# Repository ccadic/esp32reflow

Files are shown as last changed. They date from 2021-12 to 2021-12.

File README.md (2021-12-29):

# esp32reflow
Small prototype of ESP32 Reflow controller

Today's design: a small ESP32 based reflow controller. PCB made with KICAD. Enclosure made with solidworks. The features: ESP32 LOLIN32 LITE. ILI9341 2.8 display with touch option activated. MAX31865 the temperature probing. 4 buttons (3 on the panel, one on the rotary encoder).  a 110v/220v relay is also there to power the heater plate.  I'm sending the PCB to the factory . Once tested, I'll upload everything on github (opensource)

It is still a proto. I'm waiting for the PCB to arrive

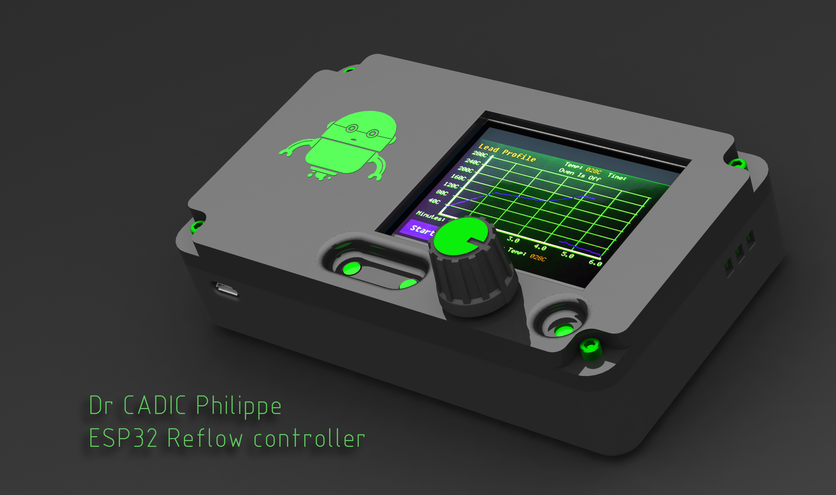
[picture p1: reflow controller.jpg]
reflow_controller


Here you have the first KICAD files
YOu also have the solidworks pre-prototyping files
ALl are subject to modification as the project gores on.

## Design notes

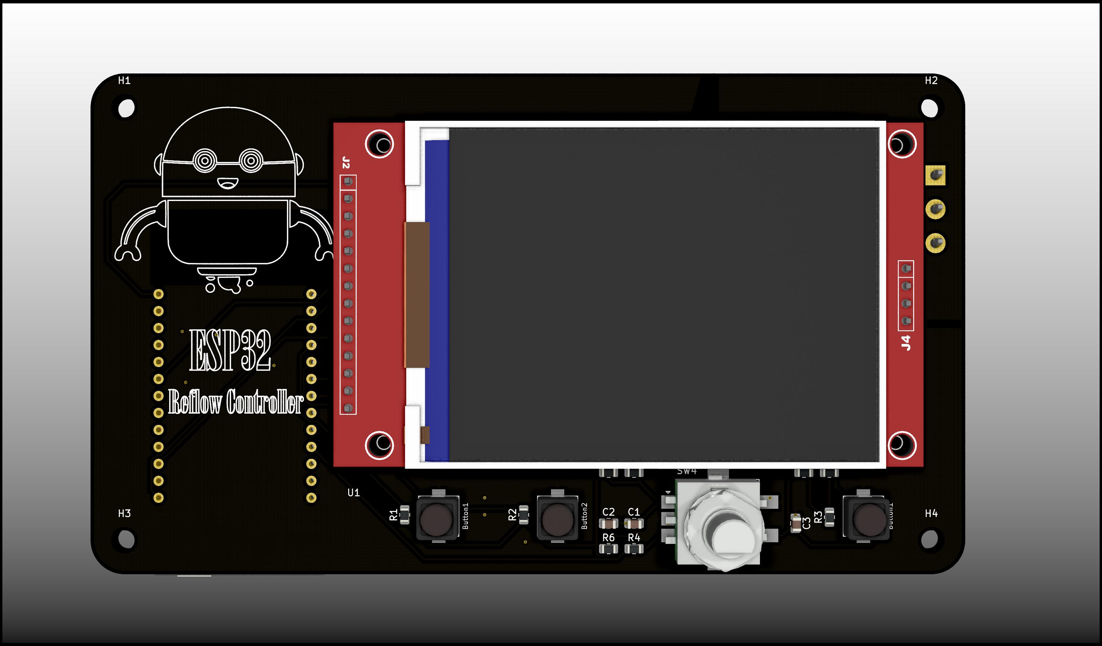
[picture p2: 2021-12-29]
esp32pcbheaterx.jpg

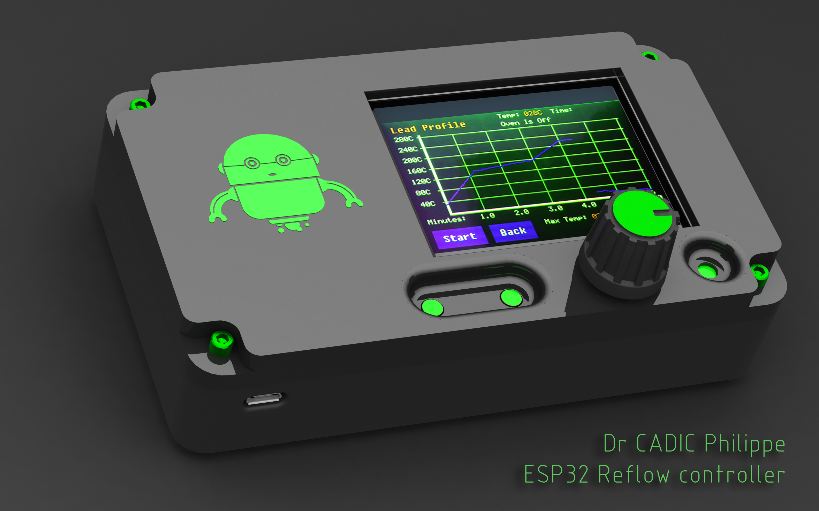
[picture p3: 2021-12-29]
reflow controller2.jpg

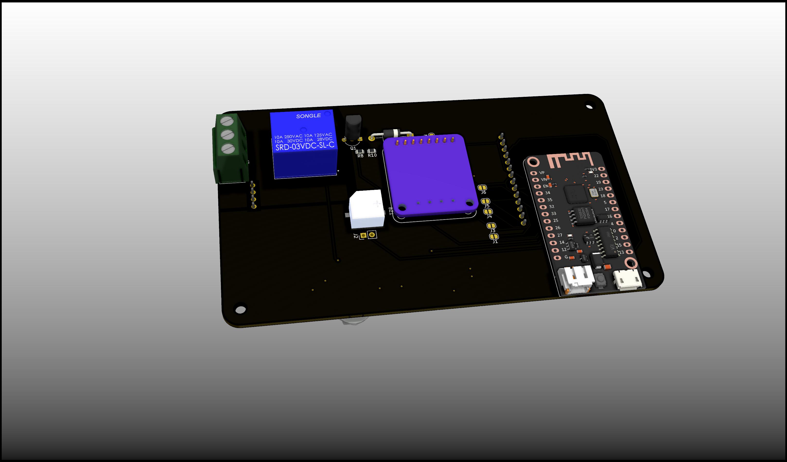
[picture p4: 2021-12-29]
esp32pcbheater2.jpg

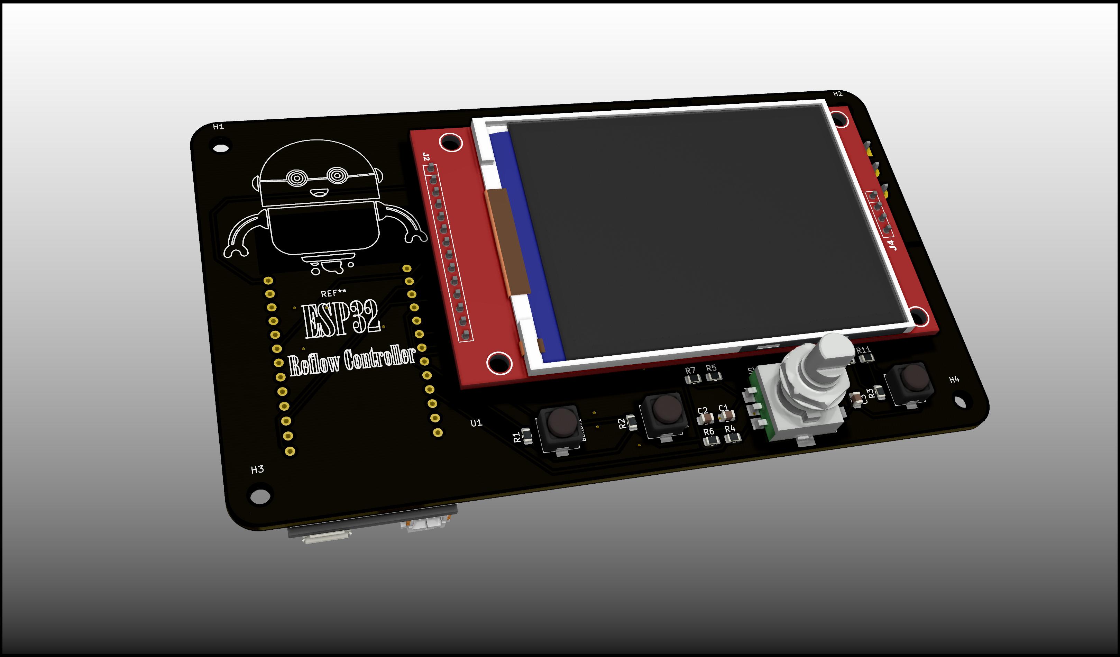
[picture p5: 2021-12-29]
esp32pcbheater.jpg

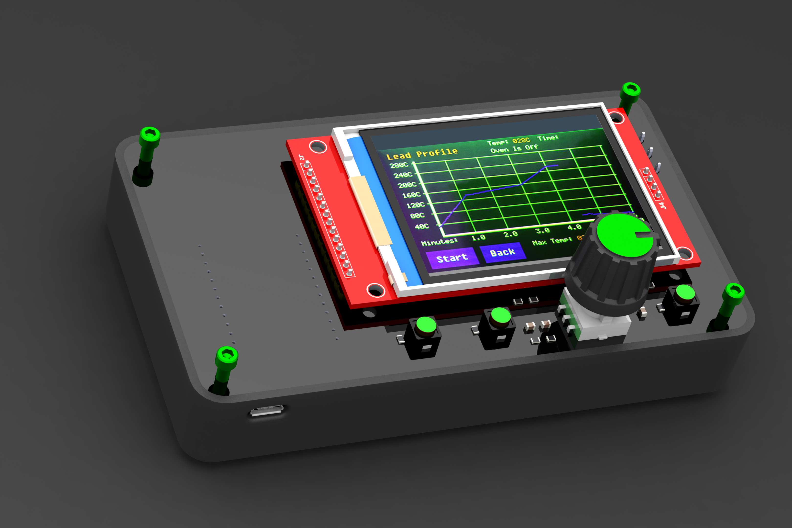
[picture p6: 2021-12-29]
z4ntitled2.JPG

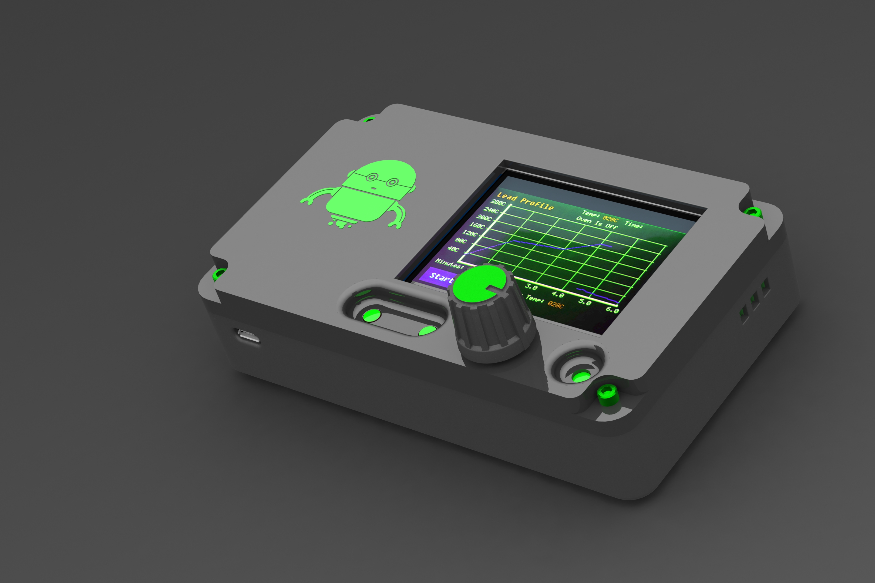
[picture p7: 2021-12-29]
Untitled2.JPG

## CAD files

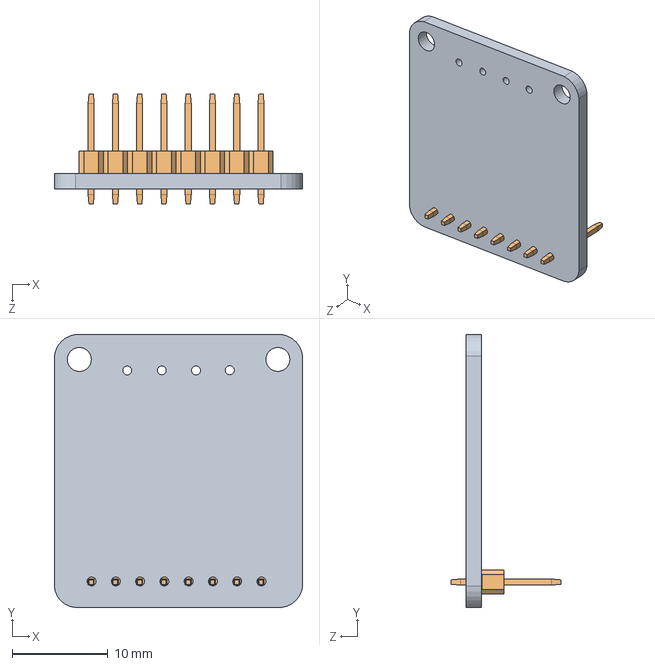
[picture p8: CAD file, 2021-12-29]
board.SLDASM
26.0 x 28.6 x 11.5 mm
minitempboard
Header, Male, 2.54mm, 1x8

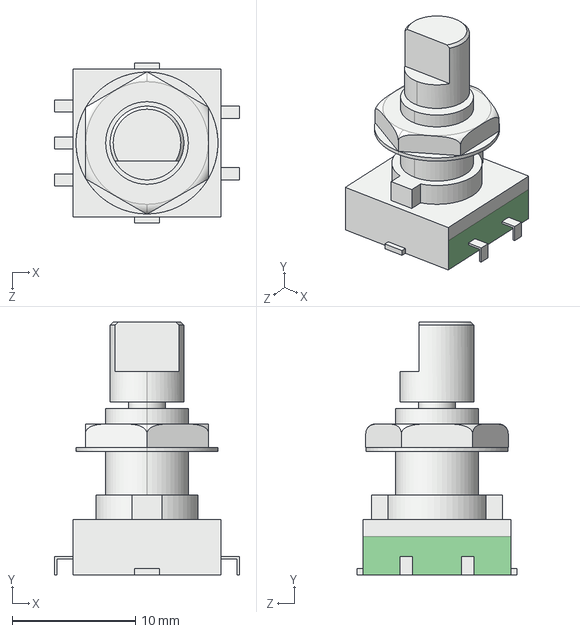
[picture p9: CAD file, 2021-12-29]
encoder-EC11.STEP
15.0 x 20.5 x 13.0 mm

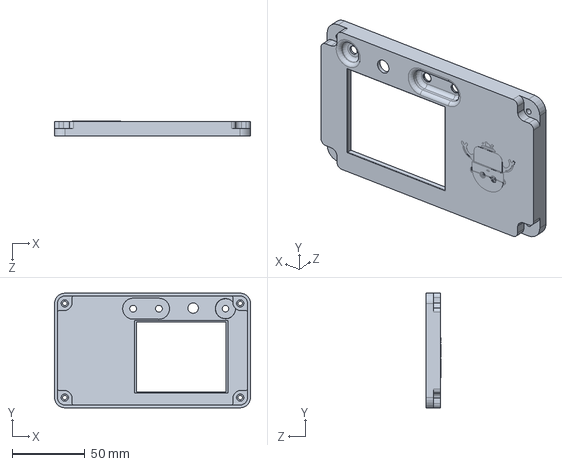
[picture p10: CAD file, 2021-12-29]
coquedessus.SLDPRT
134.8 x 78.9 x 10.1 mm

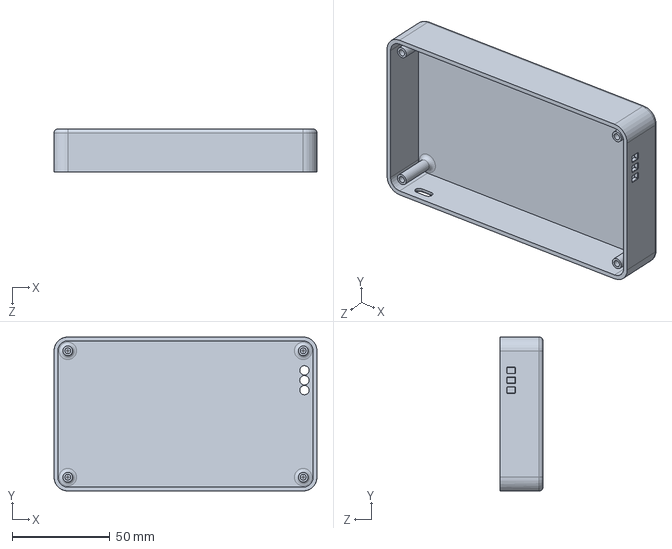
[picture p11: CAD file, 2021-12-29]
coquedessous.SLDPRT
134.8 x 78.9 x 22.0 mm

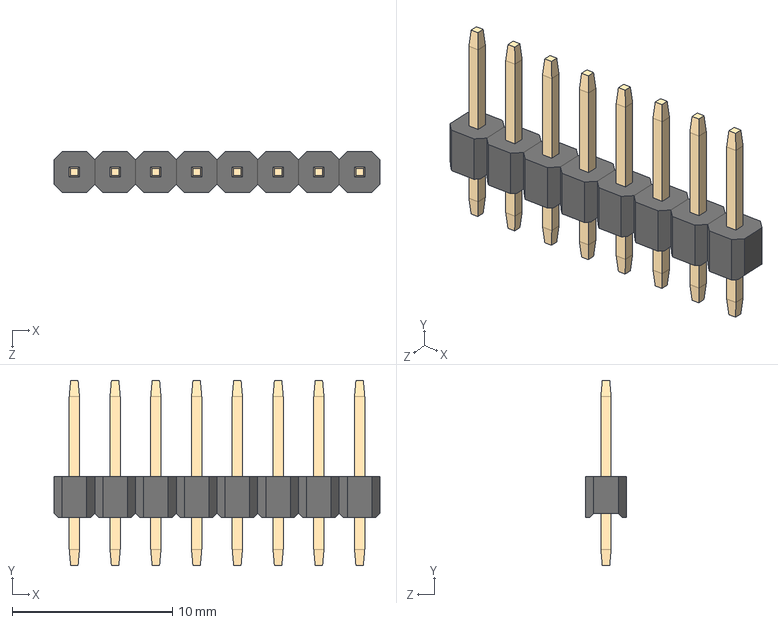
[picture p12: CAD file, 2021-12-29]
Header, Male, 2.54mm, 1x8.STEP
20.3 x 11.5 x 2.54 mm

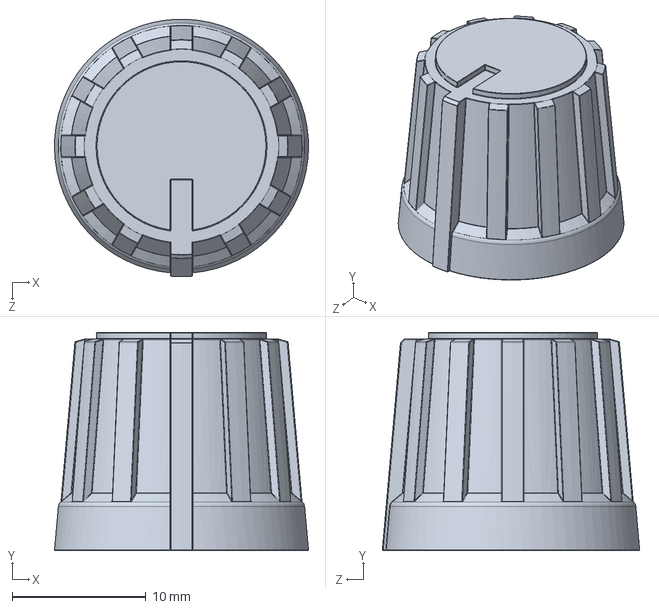
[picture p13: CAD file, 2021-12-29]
Turn knob.SLDPRT
19.0 x 16.3 x 19.2 mm

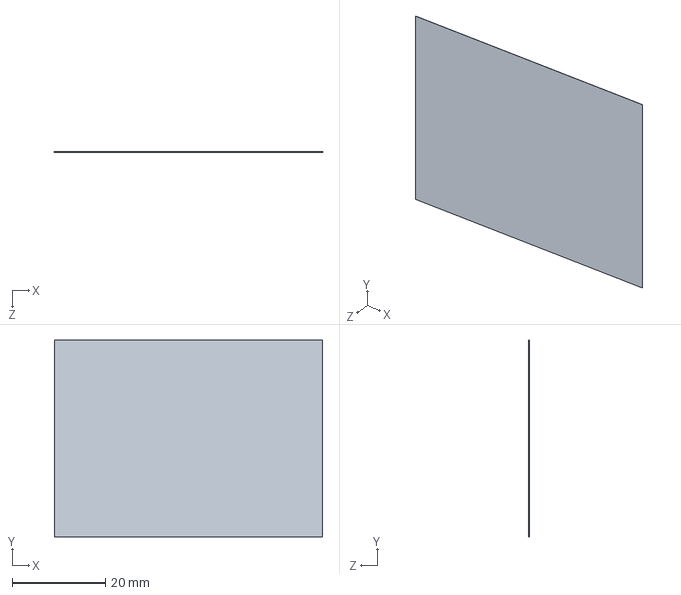
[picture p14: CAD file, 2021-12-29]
ecrandisplay.SLDPRT
57.6 x 42.3 x 0.05 mm

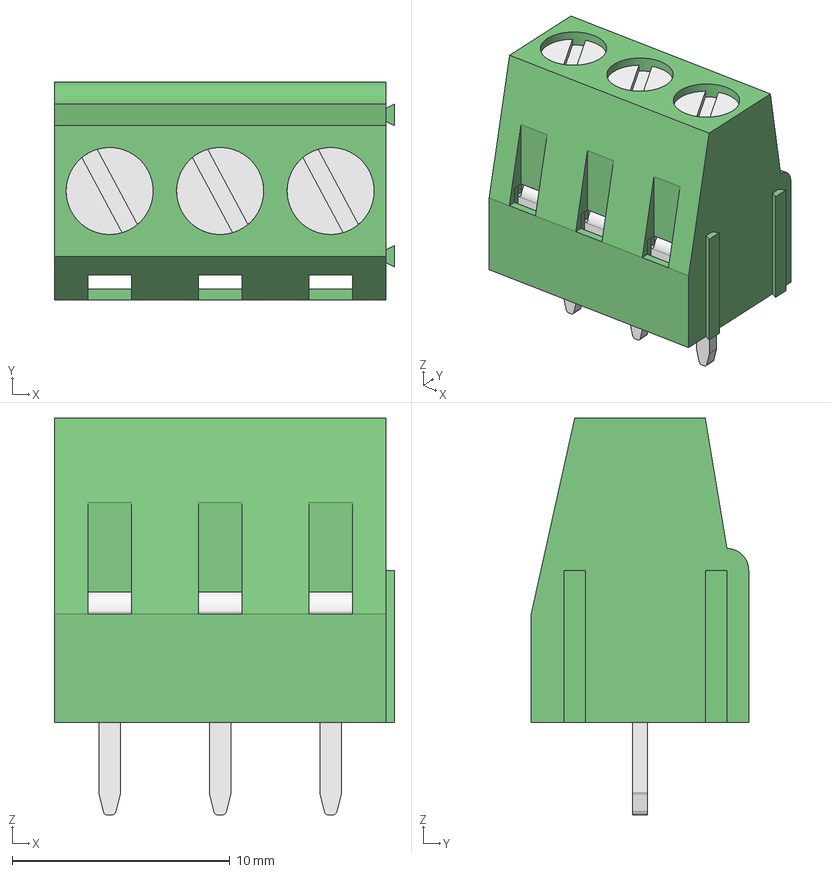
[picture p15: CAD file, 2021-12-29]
3er Terminal Block.step
15.6 x 10.0 x 18.2 mm
Pin (1) (19) (1)
Tornillo (1) (19) (1)
Cubo interno (1) (19) (1)
Pin (1) (1) (18) (1)
Tornillo (1) (1) (18) (1)
Cubo interno (1) (1) (18) (1)
Pin (1) (11) (1)
Tornillo (1) (11) (1)
Cubo interno (1) (11) (1)
Pin (1) (1) (10) (1)
Tornillo (1) (1) (10) (1)
Cubo interno (1) (1) (10) (1)
Pin (1) (17)
Tornillo (1) (17)
Cubo interno (1) (17)
Pin (1) (1) (16)
Tornillo (1) (1) (16)
Cubo interno (1) (1) (16)

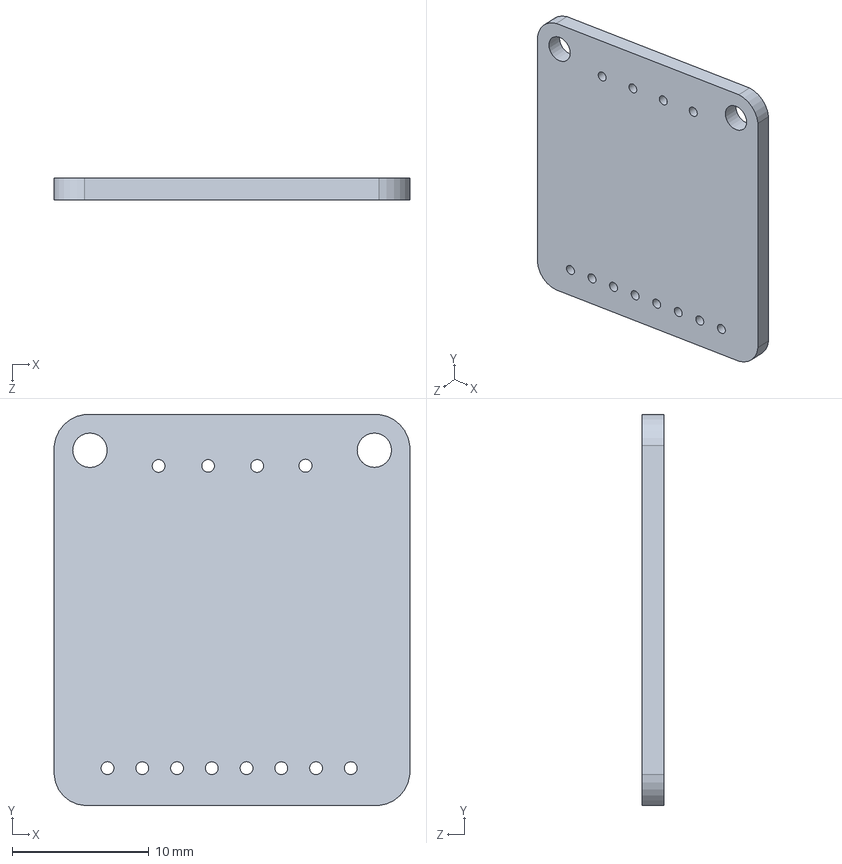
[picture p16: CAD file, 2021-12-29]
minitempboard.SLDPRT
26.0 x 28.6 x 1.60 mm

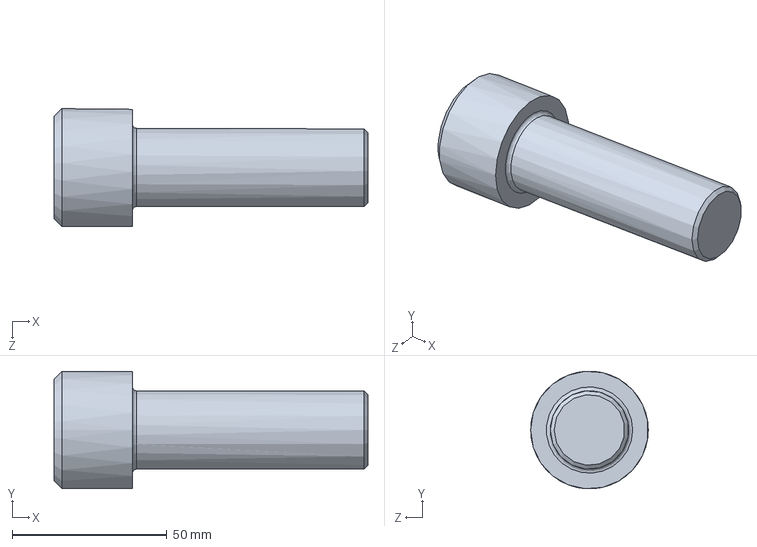
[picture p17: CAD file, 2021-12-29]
socket head cap screw_ai.SLDPRT
101.6 x 38.0 x 38.1 mm

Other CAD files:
MAX31865 RTD.STEP
Header, Male, 2.54mm, 1x8.SLDPRT

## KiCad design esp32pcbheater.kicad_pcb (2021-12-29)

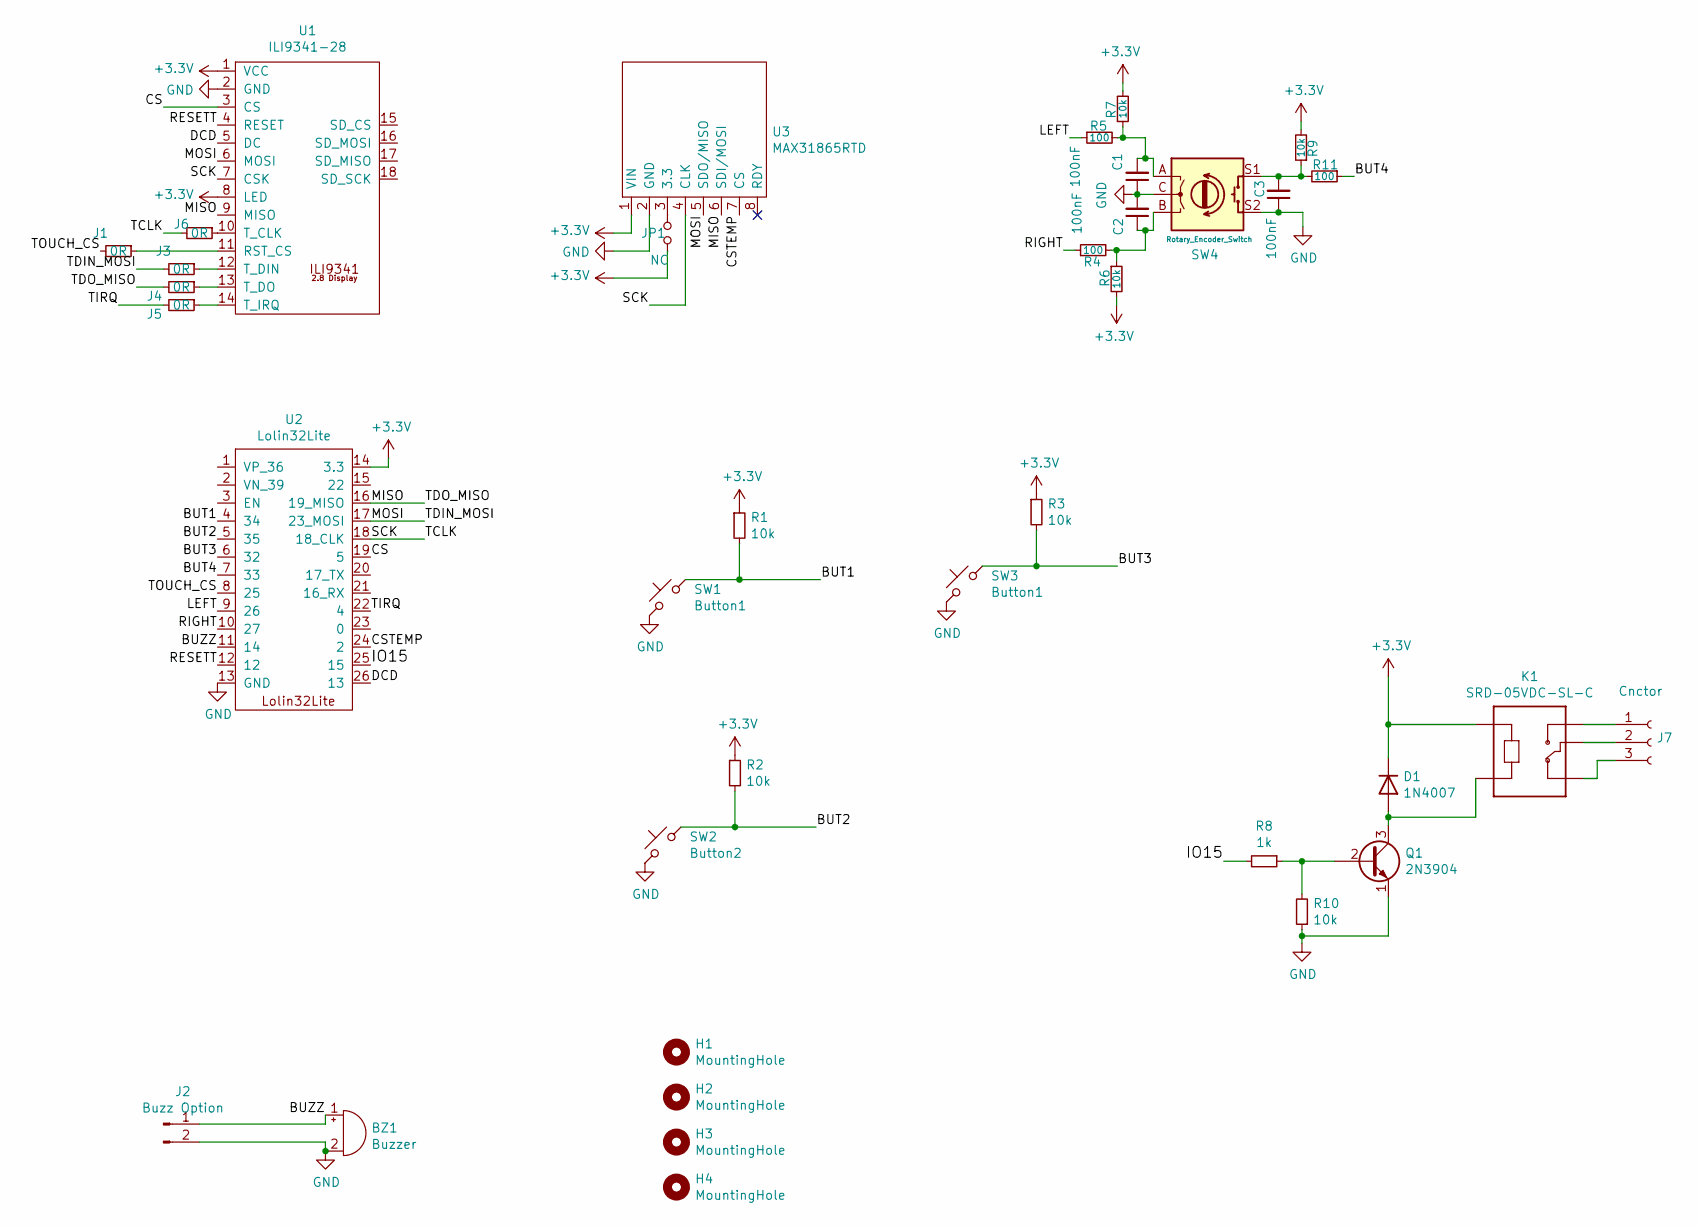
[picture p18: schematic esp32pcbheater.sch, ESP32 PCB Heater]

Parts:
BZ1: Buzzer; Buzzer93
C1, C2, C3: 100nF; C_0805_2012Metric
D1: 1N4007; D_DO-41_SOD81_P12.70mm_Horizontal
H1, H2, H3, H4: MountingHole; MountingHole_3mm
J1, J3, J4, J5, J6: 0R; SolderJumper-2_P1.3mm_Open_RoundedPad1.0x1.5mm
J2: Buzz Option; PinHeader_1x02_P2.54mm_Vertical
J7: Cnctor; TerminalBlock_bornier-3_P5.08mm
JP1: NC; JumperSmall
K1: SRD-05VDC-SL-C; RELAY_SRD-05VDC-SL-C
Q1: 2N3904; TO-92L_Inline_Wide
R1, R2, R3, R6, R7, R9, R10: 10k; R_0805_2012Metric
R4, R5, R11: 100; R_0805_2012Metric
R8: 1k; R_0805_2012Metric
SW1, SW3: Button1; SW_TP1003
SW2: Button2; SW_TP1003
SW4: Rotary_Encoder_Switch; RotaryEncoder_Alps_EC11E-Switch_Vertical_H20mm
U1: ILI9341-28; ILI9341-2_8
U2: Lolin32Lite; LOLIN32Lite
U3: MAX31865RTD; MAX31865PCB

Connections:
+3V3: D1.1 (K), JP1.2, K1.1 (A1), R1.1, R2.1, R3.1, R6.2, R7.2, R9.2, U1.1 (VCC), U1.8 (LED), U2.14 (3.3), U3.1 (VIN)
/BUT1: R1.2, SW1.2, U2.4 (34)
/BUT2: R2.2, SW2.2, U2.5 (35)
/BUT3: R3.2, SW3.2, U2.6 (32)
/BUT4: R11.1, U2.7 (33)
/BUZZ: BZ1.1 (-), J2.1, U2.11 (14)
/CS: U1.3 (CS), U2.19 (5)
/CSTEMP: U2.24 (2), U3.7 (CS)
/DCD: U1.5 (DC), U2.26 (13)
/IO15: R8.2, U2.25 (15)
/LEFT: R5.1, U2.9 (26)
/MISO: J4.2, U1.9 (MISO), U2.16 (19_MISO), U3.6 (SDI/MOSI)
/MOSI: J3.2, U1.6 (MOSI), U2.17 (23_MOSI), U3.5 (SDO/MISO)
/RESETT: U1.4 (RESET), U2.12
/RIGHT: R4.1, U2.10 (27)
/SCK: J6.2, U1.7 (CSK), U2.18 (18_CLK), U3.4 (CLK)
/TIRQ: J5.2, U2.22 (4)
/TOUCH_CS: J1.2, U2.8 (25)
GND: BZ1.2 (+), C1.1, C2.2, C3.1, J2.2, Q1.1 (E), R10.1, SW1.1, SW2.1, SW3.1, SW4.C, SW4.S2, U1.2 (GND), U2.13 (GND), U3.2 (GND)
unnamed: C1.2, R5.2, R7.1, SW4.A
unnamed: C2.1, R4.2, R6.1, SW4.B
unnamed: C3.2, R9.1, R11.2, SW4.S1
unnamed: D1.2 (A), K1.4 (A2), Q1.3 (C)
unnamed: J1.1, U1.11 (RST_CS)
unnamed: J3.1, U1.12 (T_DIN)
unnamed: J4.1, U1.13 (T_DO)
unnamed: J5.1, U1.14 (T_IRQ)
unnamed: J6.1, U1.10 (T_CLK)
unnamed: J7.1, K1.3 (NO)
unnamed: J7.2, K1.5 (COM)
unnamed: J7.3, K1.2 (NC)
unnamed: JP1.1, U3.3 (3.3)
unnamed: Q1.2 (B), R8.1, R10.2

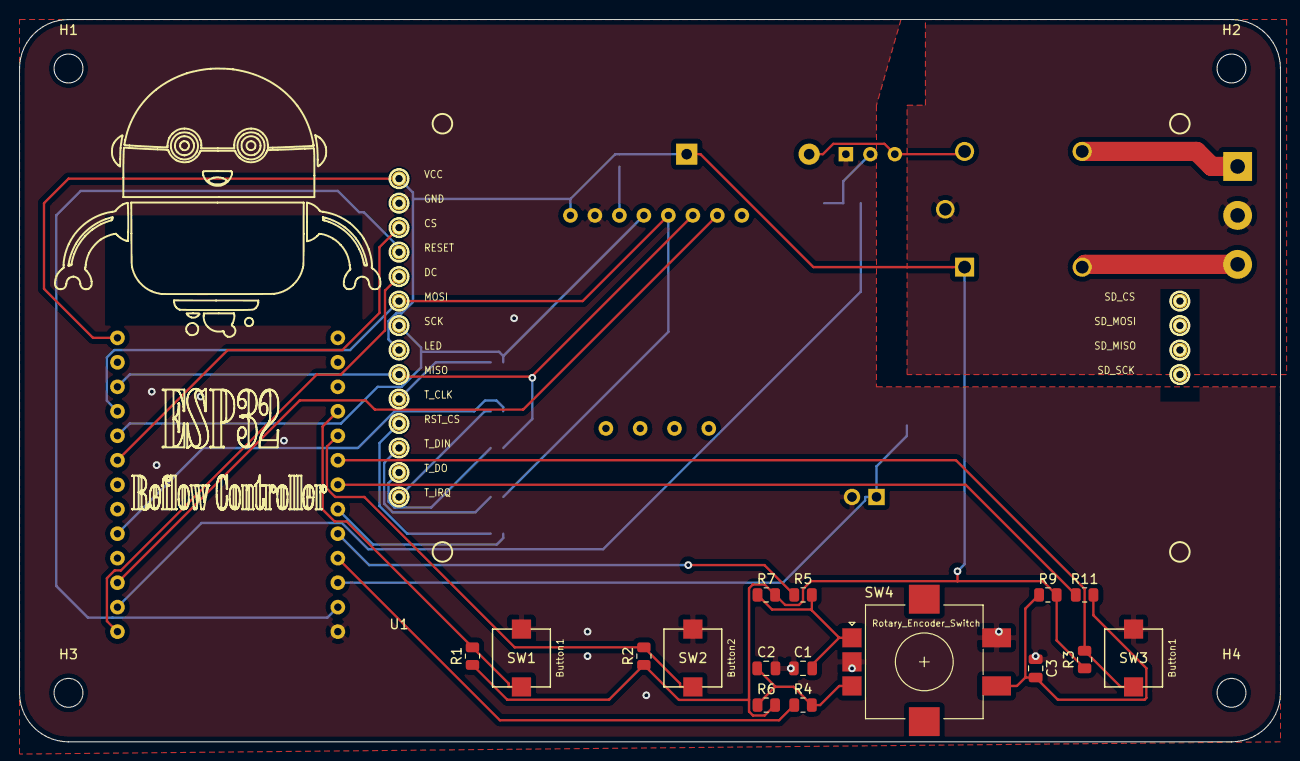
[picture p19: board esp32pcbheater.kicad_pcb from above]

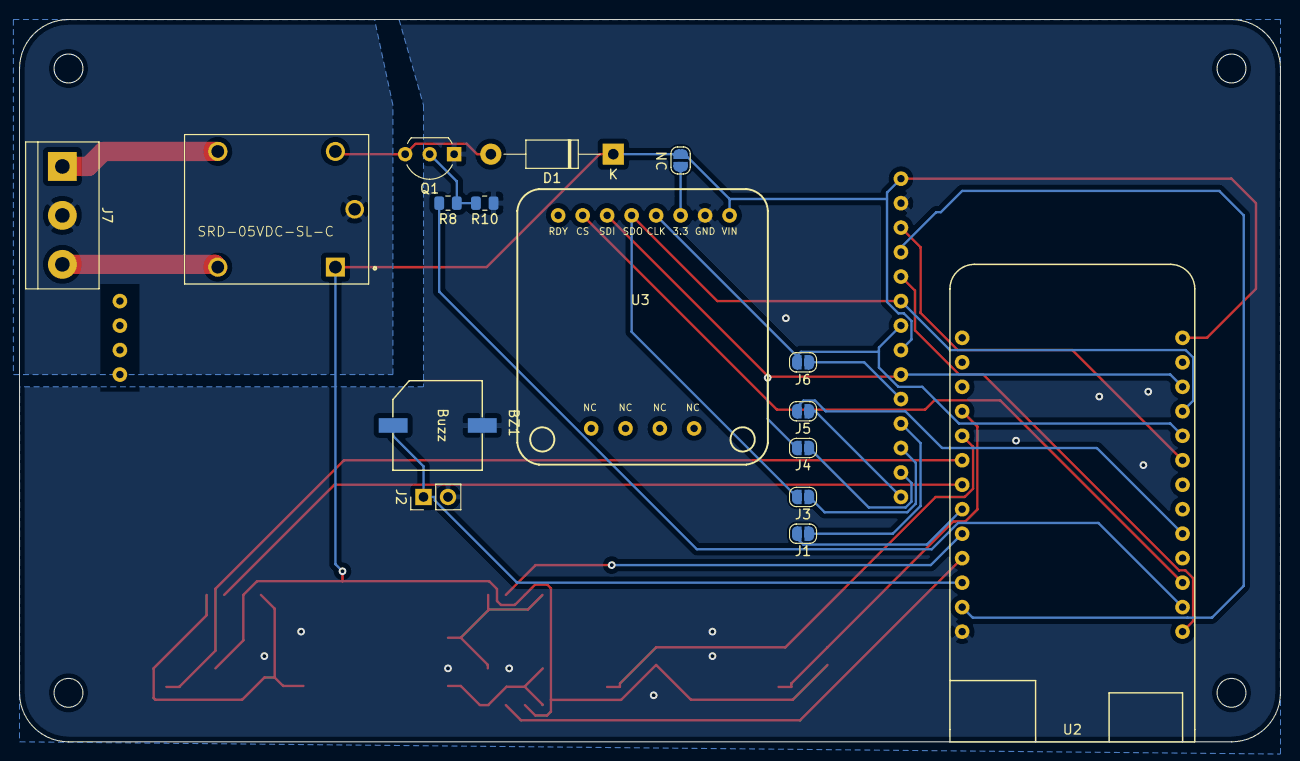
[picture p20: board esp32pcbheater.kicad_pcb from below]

Board: 2 copper layers, 130.8 x 74.9 mm, 37 parts (16 on the bottom side), 33 nets.
